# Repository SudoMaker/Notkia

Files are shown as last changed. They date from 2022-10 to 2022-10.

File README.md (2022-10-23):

# Notkia

Files of the [Notkia project on Hackaday](https://hackaday.io/project/185645-notkia).

EE4A1119__22

## Notice
This is only a DIY/maker/hobbyist project. **It has NOTHING to do with the Nokia Corporation.**

**The "NOKIA" logo and trademark belongs to the Nokia Corporation.**

## Contents
**Software** - Kernel patches, config, code, etc

**Hardware** - Hardware design files

**Resources** - Support materials like the docs of used components

## Quick guide
Follow the build instructions on the Hackaday page.

[Firmware download](https://drive.google.com/drive/folders/1oXkI3N4dK0Gwsrb4oEOyaak5tPrkD-Ys?usp=sharing)

When the system is booted, you can connect USB cable and log into the device using the 2nd USB CDC-ACM device. USB RNDIS network is also activated at 192.168.77.2/24 w/o DHCP. SSH login information is root:notkia.

Happy hacking!

## Notes
If you have any questions, feel free to ask on our Twitter / Discord.

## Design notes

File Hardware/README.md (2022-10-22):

# Hardware

## Contents
**V2.0** - The V2.0 Notkia PCB

**SoM_V1.3** - The X1000 SoM used on the V2.0 Notkia PCB

## Usage
### Producing
The Gerber and SMT files can be used to produce the PCBs directly.

### Editing
The standard version of EasyEDA was used to design this project.

At editor, open the document via: Top Menu - File - Open - EasyEDA... , and select the json file, then open it at the editor, you can save it into a project.

## License
CERN-OHL2-S

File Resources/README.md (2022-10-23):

# Resources

## Description

Datasheets and support materials of components that are not easy to find on the Internet are uploaded here.

Information of the rest components can be find on the Internet within a few minutes.

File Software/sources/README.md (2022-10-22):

# Sources

## Contents
**lora** - Mini proof-of-concept LoRa messenger. Hardcoded at 433.92Mhz/22dBm/SF12/62.5kHz.

**t9uinput** - Mini proof-of-concept T9 IME.

**blanker.c** - Zero the VRAM of ST7789. Unbind FBTFT driver before use.

**lvgl_demo.c** - LVGL demo (music player/stress test). Unbind FBTFT driver before use.

## Credits
**ST7789-STM32** - https://github.com/Floyd-Fish/ST7789-STM32

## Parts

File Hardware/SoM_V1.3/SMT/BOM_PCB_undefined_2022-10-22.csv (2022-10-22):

ID | Name | Designator | Footprint | Quantity | Manufacturer Part | Manufacturer | Supplier | Supplier Part | Price
1 | 24MHz | X1 | OSC-SMD_4P-L2.0-W1.6-BL | 1 | Q22FA12800244 | Seiko Epson | LCSC | C255880 | 1.6628
2 | LDO UDFN-4/XDFN-4 大焊盘 | U35,U36 | UDFN-4_L1.0-W1.0-P0.65-BL-EP 焊盘加大 | 2 |  |  | LCSC
3 | 10uF | C5,C6,C8,C9,C12,C16,C18,C19,C28,C116,C120 | C0402 | 11 | CL05A106MQ5NUNC | SAMSUNG | LCSC | C15525 | 0.0328
4 | 22pF | C3,C22,C23,C24,C4,C130 | C0201 | 6 | GRM0335C1H220JA01D | MuRata | LCSC | C76924 | 0.0138
5 | 1uF | C21,C25,C26,C1,C7,C42,C86,C99,C100,C112,C113,C118,C13,C15,C30 | C0201 | 15 | JMK063ABJ105MP-F | TAIYO YUDEN | LCSC | C87143 | 0.0117
6 | 330K | R10,R13,R14,R3,R1,R11 | R0201 | 6 | RC0201FR-07330KL | YAGEO | LCSC | C142017 | 0.0061
7 | 1MΩ | R15,R6 | R0201 | 2 | RTT011004FTH | RALEC | LCSC | C102686 | 0.0062
8 | 4.7kΩ | R16 | R0201 | 1 | 0201WMF4701TEE | Uniroyal Elec | LCSC | C270346 | 0.005
9 | 10MΩ | R17 | R0201 | 1 | 0201WMF1005TCE | Uniroyal Elec | LCSC | C270818 | 0.0214
10 | 32.768kHz | X2 | FC-12M_L2.0-W1.2 | 1 | FC-12M32.768KHZ7PF20PPM | EPSON | LCSC | C99009 | 1.7615
11 | 1K | R7 | R0201 | 1 | RC0201JR-071KL | YAGEO | LCSC | C131396 | 0.0044
12 | 240Ω | R8 | R0201 | 1 | RTT01241JTH | RALEC | LCSC | C102710 | 0.0039
13 | 43.2Ω | R12 | R0201 | 1 | RTT0143R2FTH | RALEC | LCSC | C158511 | 0.0062
14 | 178kΩ | R4 | R0201 | 1 | 0201WMF1783TCE | Uniroyal Elec | LCSC | C270786 | 0.0098
15 | 100 | R9 | R0201 | 1 | RC0201FR-07100RL | YAGEO | LCSC | C77623 | 0.0056
16 | 100nF | C11,C2,C10,C33,C46,C48,C49,C51,C82,C98,C101,C117,C129,C131,C14 | C0201 | 15 | CL03A104KQ3NNNC | SAMSUNG | LCSC | C160831 | 0.0036
17 | 10nF | C32,C80,C102,C132,C97 | C0201 | 5 | GRM033R71E103KE14D | MuRata | LCSC | C85930 | 0.011
18 | 2.2uH | L1,L2,L3 | IND-SMD_L2.0-W1.6 | 3 | WPN201610U2R2MTY01 | Sunlord | LCSC | C370597 | 0.3682
19 | 100kΩ | R2 | R0402 | 1 | 0402WGF1003TCE | UniOhm | LCSC | C25741 | 0.0029
20 | 200kΩ | R5 | R0402 | 1 | 0402WGF2003TCE | UniOhm | LCSC | C25764 | 0.0029
21 | 124kΩ | R59 | R0402 | 1 | 0402WGF1243TCE | UniOhm | LCSC | C36777 | 0.0032
22 | 115kΩ | R60 | R0402 | 1 | 0402WGF1153TCE | UniOhm | LCSC | C25747 | 0.0036
23 | X1000 | U1 | BGA-190_L13.0-W13.0-R16-C16-P0.8-TR | 1 | X1000 | ingenic(君正) | LCSC | C2689394 | 47.65
24 | TPS63000DRCR | U32 | SON-10_L3.1-W3.1-P0.50-TL-EP | 1 | TPS63000DRCR | TI | LCSC | C24966 | 110.32
25 | RT8010GQW | U33,U34 | WDFN-6_L2.0-W2.0-P0.65-BL-EP | 2 | RT8010GQW | RICHTEK | LCSC | C130803 | 2.15
26 | 10kΩ | RN1 | RES-ARRAY-SMD_0402-8P-L2.0-W1.0-BL | 1 | 4D02WGJ0103TCE | UniOhm | LCSC | C25725 | 0.0318
27 | W25Q256JVEIQ | U16 | WSON-8_L6.0-W8.0-P1.27-BL-EP | 1 | W25Q256JVEIQ | WINBOND(华邦) | LCSC | C2682312 | 11.28

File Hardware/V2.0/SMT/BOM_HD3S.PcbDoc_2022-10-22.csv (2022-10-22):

ID | Name | Designator | Footprint | Quantity | Manufacturer Part | Manufacturer | Supplier | Supplier Part | Price
1 | JW_S-5012-A | J17 | JW_S-5012-A | 1
2 | N168X_Key | K1,K2,K3,K4,K5,K6,K7,K8,K9,K10,K11,K12,K13,K14,K15,K16,K17,K18,K19,K20,K21 | N168X_KEY | 21
3 | TZ-P2-0603WYS1-1.1T | LED1,LED2 | LED-SMD_L1.6-W1.2-RD | 2 | TZ-P2-0603WYS1-1.1T | TUOZHAN | LCSC | C916072 | 0.1172
4 | GPS1003 | ANT2 | ANT-SMD_L10.0-W3.0 | 1 | GPS1003 | Rainsun microwave Tech | LCSC | C239243 | 6.76
5 | 1uF | C16,C43,C46,C47,C48,C50,C15,C28,C32,C21,C22,C26,C27,C20,C34,C5,C6,C7,C23 | C0402 | 19 | CL05A105KA5NQNC | SAMSUNG | LCSC | C52923 | 0.0203
6 | WD3153D-10/TR | U3 | DFN-10_L2.0-W2.0-P0.40-BL-EP | 1 | WD3153D-10/TR | WILLSEMI(韦尔) | LCSC | C506151 | 0.3361
7 | TP | Q6,Q5,Q3,Q4 | TP | 4 | TP
8 | UBX-G7020-KT | U18 | UBX-G7020-KT | 1
9 | 47pF | C33 | C0402 | 1 | 0402CG470J500NT | FH | LCSC | C1567 | 0.0054
10 | 2.7pF | C41 | C0402 | 1 | 0402CG2R7C500NT | FH | LCSC | C1561 | 0.0071
11 | 4.7uF | C24,C25,C35,C37,C44,C49,C59,C60,C62,C64,C65,C66,C71,C74,C75,C122 | C0402 | 16 | CL05A475MP5NRNC | SAMSUNG | LCSC | C23733 | 0.0327
12 | 2.2uF | C45 | C0402 | 1 | CL05A225MQ5NSNC | SAMSUNG | LCSC | C12530 | 0.012
13 | 8.2nH | L1 | IND-SMD_L1.0-W0.5-2 | 1 | LQW15AN8N2G00D | MuRata | LCSC | C84404 | 0.2212
14 | 2.2uH | L3 | L0806 | 1 | LQM2MPN2R2NG0L | MuRata | LCSC | C83998 | 0.4232
15 | 26MHz | X2 | OSC-SMD_4P-L3.2-W2.5-BL_1XTV | 1 | 1XTW26000MAA | KDS Daishinku | LCSC | C213404 | 6.34
16 | 2.2K | R1,R2,R12,R13 | R0402 | 4 | 0402WGF2201TCE | UniOhm | LCSC | C25879 | 0.0029
17 | X1000_Nano | U1 | X1000_NANO | 1 | X1000_Nano | SudoMaker
18 | VRD1528MTX | U33 | SOT-23-6_L2.9-W1.6-P0.95-LS2.8-BL | 1 | VRD1528MTX | AnaSem | LCSC | C697914 | 0.5386
19 | FH34SRJ-12S-0.5SH(50) | FPC1 | FFC-SMD_12P-P0.50_FH34SRJ-12S-0.5SH | 1 | FH34SRJ-12S-0.5SH(50) | Hirose | LCSC | C424659 | 1.0982
20 | 33kΩ | RN3,RN1,RN2 | RES-ARRAY-SMD_0402-8P-L2.0-W1.0-BL | 3 | WA04X333JTL | Walsin Tech Corp | LCSC | C431861 | 0.0305
21 | 47uF | C11,C18 | C0805 | 2 | CL21A476MQYNNNE | SAMSUNG | LCSC | C16780 | 0.0682
22 | RFANT3216120A5T | ANT1 | FILTER-SMD_1206-2P-L3.2-W1.6-L | 1 | RFANT3216120A5T | Walsin Tech Corp | LCSC | C127629 | 0.536
23 | 100nF | C14,C40,C42,C38,C19,C1,C4,C8,C10,C12 | C0402_NEW | 10 | CL05B104KO5NNNC | SAMSUNG | LCSC | C1525 | 0.0062
24 | PCA9555RGERG4 | U2,U8,U141 | VQFN-24_L4.0-W4.0-P0.50-TL-EP2.4 | 3 | PCA9555RGERG4 | TI(德州仪器) | LCSC | C2669780 | 9.57
25 | FH34SRJ-24S-0.5SH(50) | CONN1 | FFC-SMD_24P-P0.50_FH34SRJ-24S-0.5SH | 1 | FH34SRJ-24S-0.5SH(50) | Hirose | LCSC | C324726 | 1.114
26 | HSST3139 | Q1,Q2 | SOT-523-3_L1.6-W0.8-P1.00-LS1.6-BR | 2 | HSST3139 | HUASHUO(华朔) | LCSC | C700948 | 0.3076
27 | 1TS026A-1800-0553-CT | SW1 | SW-SMD_4P-L2.6-W1.6-P0.75-LS3.0 | 1 | 1TS026A-1800-0553-CT | HYP(鸿源精密) | LCSC | C913786 | 0.5711
28 | 33kΩ | R7,R18,R3,R29,R4,R8,R10,R11 | R0402 | 8 | 0402WGF3302TCE | UniOhm | LCSC | C25779 | 0.0029
29 | HJ_LORA | U64 | HJ_LORA | 1
30 | MKDV32GCL-STL | U16 | W-PDFN-8_L8.0-W6.0-P1.27-TL-EP | 1 | MKDV32GCL-STL | MK(米客方德) | LCSC | C2844071 | 53.05
31 | MHS110FRGBCT | LED16 | LED-ARRAY-SMD_MHS110FRGBCT | 1 | MHS110FRGBCT | MEIHUA(美华科技) | LCSC | C496820 | 0.4385
32 | N68_BATJ | BAT1 | N68_BATJ | 1
33 | TYPE-611S-T3 | USB1 | USB-SMD_TYPE-611S-T3 | 1 | TYPE-611S-T3 | Yuandi(台湾元迪) | LCSC | C2874595 | 0.727
34 | 1N5819WS | D3,D1 | SOD-323_L1.8-W1.3-LS2.5-RD | 2 | 1N5819WS | Guangdong Hottech | LCSC | C191023 | 0.101
35 | RX8900CE | U204 | RX8130CE/RX8900CE | 1 | RX8900CE | EPSON
36 | 1kΩ | R20 | R0603 | 1 | 0603WAF1001T5E | UniOhm | LCSC | C21190 | 0.0027
37 | 10uF | C2,C9,C13,C39,C134 | C0402 | 5 | CL05A106MQ5NUNC | SAMSUNG | LCSC | C15525 | 0.0328
38 | 3.3K | R19 | R0402 | 1 | 0402WGF3301TCE | UniOhm | LCSC | C25890 | 0.0029
39 | 100nF | C29,C30,C36 | C0402 | 3 | CL05B104KO5NNNC | SAMSUNG | LCSC | C1525 | 0.0062
40 | 12.288MHz | X1 | OSC-SMD_4P-L2.0-W1.6-BL_SIT1602BI | 1 | OT201624MJBA4SL | YXC扬兴科技 | LCSC | C725986 | 4.41
41 | 1nF | C31 | C0402 | 1 | 0402B102K500NT | FH | LCSC | C1523 | 0.0061
42 | YMU762 | U140 | C-PK32QP-2 | 1
43 | 20kΩ | R14,R15,R16,R17 | R0402 | 4 | 0402WGF2002TCE | UniOhm | LCSC | C25765 | 0.0029
44 | BCT8890ELA-TR | U129,U130 | DFN-8_L2.0-W2.0-P0.50-BL-EP-1 | 2 | BCT8890ELA-TR | BROADCHIP(广芯电子) | LCSC | C2924400 | 1.0485
45 | SHTC3 | U41 | SENSORM-SMD_4P-L2.0-W2.0-P1.00 | 1 | SHTC3 | Sensirion | LCSC | C194656 | 5.88
46 | FUSB301TMX | U135 | TMLP-10_L1.6-W1.2-P0.40 | 1 | FUSB301TMX | ON | LCSC | C132290 | 7.64
47 | 0Ω | R49,R54 | R0402 | 2 | 0402WGF0000TCE | UniOhm | LCSC | C17168 | 0.0028
48 | A_P6214 | U48 | AP6214A | 1
49 | NAU88C22YG | U128 | QFN-32_L5.0-W5.0-P0.50-BL-EP3.4 | 1 | NAU88C22YG | NUVOTON | LCSC | C100123 | 6.7
50 | 22uF | C135,C136 | C0603 | 2 | CL10A226MQ8NRNC | SAMSUNG | LCSC | C59461 | 0.0292
51 | 1uH | L4 | IND-SMD_L2.5-W2.0_252012 | 1 | HHEI252010A-1R0M-Q8 | chilisin(奇力新) | LCSC | C910025 | 0.5405
52 | BQ25890RTWR | U32 | WQFN-24_L4.0-W4.0-P0.50-BL-EP | 1 | BQ25890RTWR | TI | LCSC | C130451 | 37.44
53 | MAX17048G+T10 | U39 | DFN-8_L2.0-W2.0-P0.50-BL-EP | 1 | MAX17048G+T10 | MAXIM(美信) | LCSC | C2682616 | 6.35
54 | 47nF | C3 | C0402 | 1 | 0402B473K250CT | Walsin Tech Corp | LCSC | C314287 | 0.008
55 | N126x_EAR | J1,J2 | N126X_EAR | 2
56 | WMM7037AT2 | MIC1 | MIC-SMD_L3.8-W3.00-TL | 1 | WMM7037AT2 | WEIER | LCSC | C140705 | 2.39
57 | 3.3uH | L2 | L0805 | 1 | MPL2012S3R3MHT | Sunlord | LCSC | C98331 | 0.1947

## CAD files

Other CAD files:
Resources/2.0 S-5012-A(3).dwg

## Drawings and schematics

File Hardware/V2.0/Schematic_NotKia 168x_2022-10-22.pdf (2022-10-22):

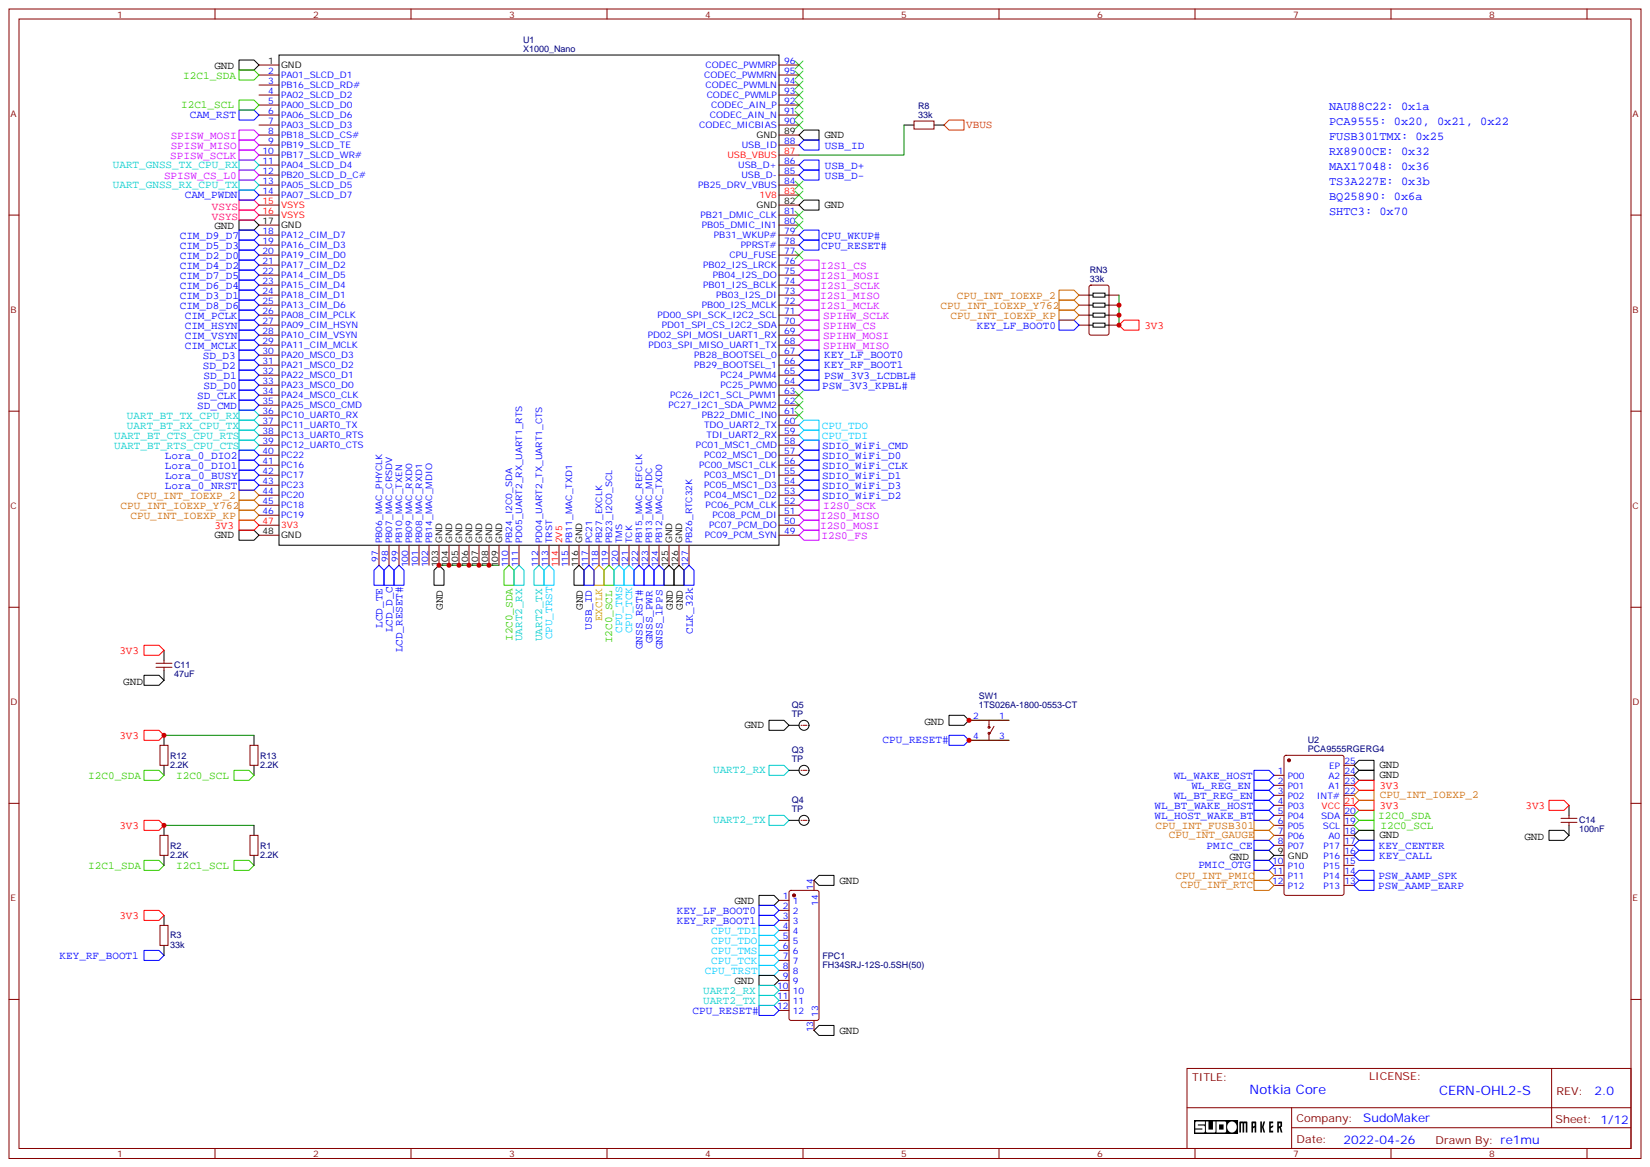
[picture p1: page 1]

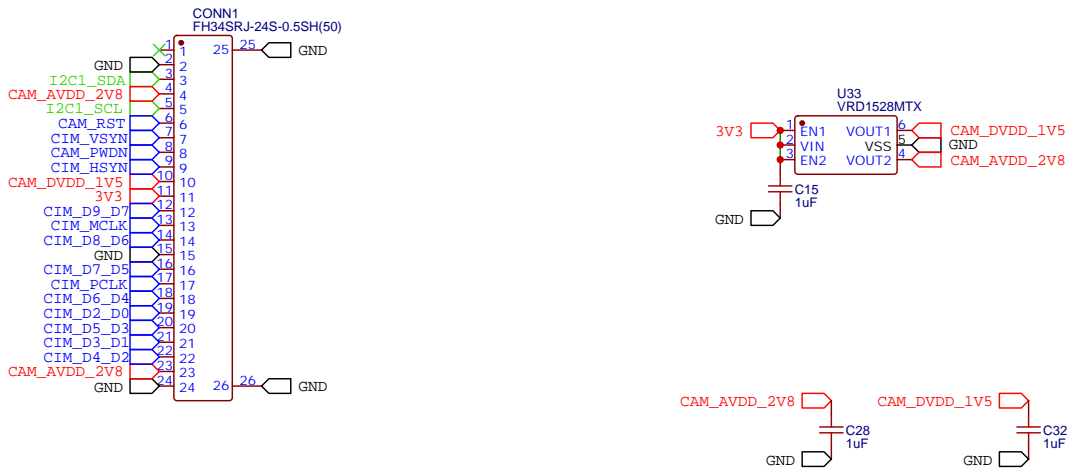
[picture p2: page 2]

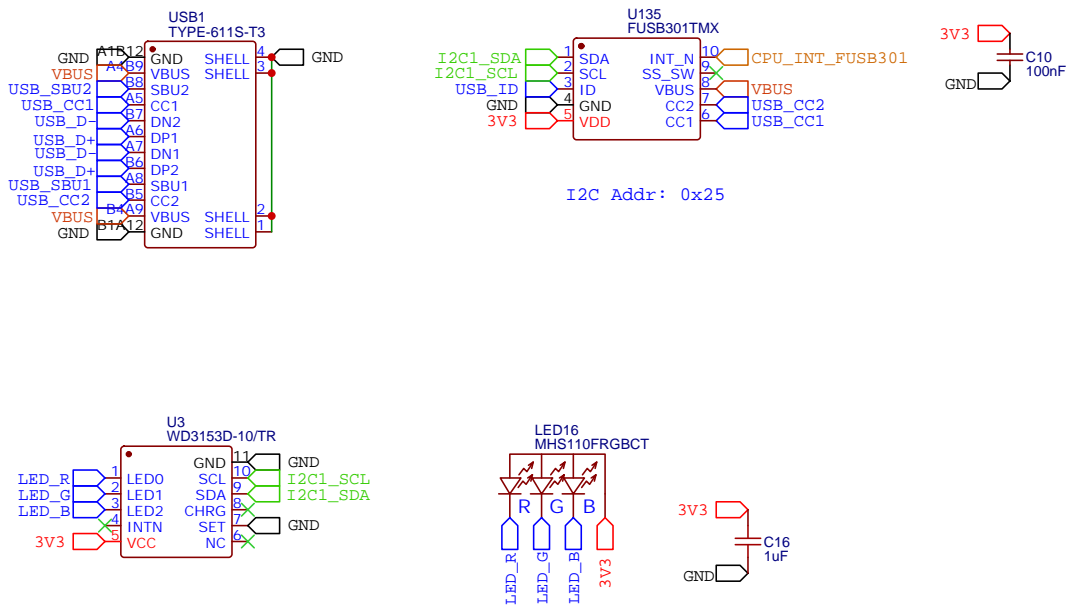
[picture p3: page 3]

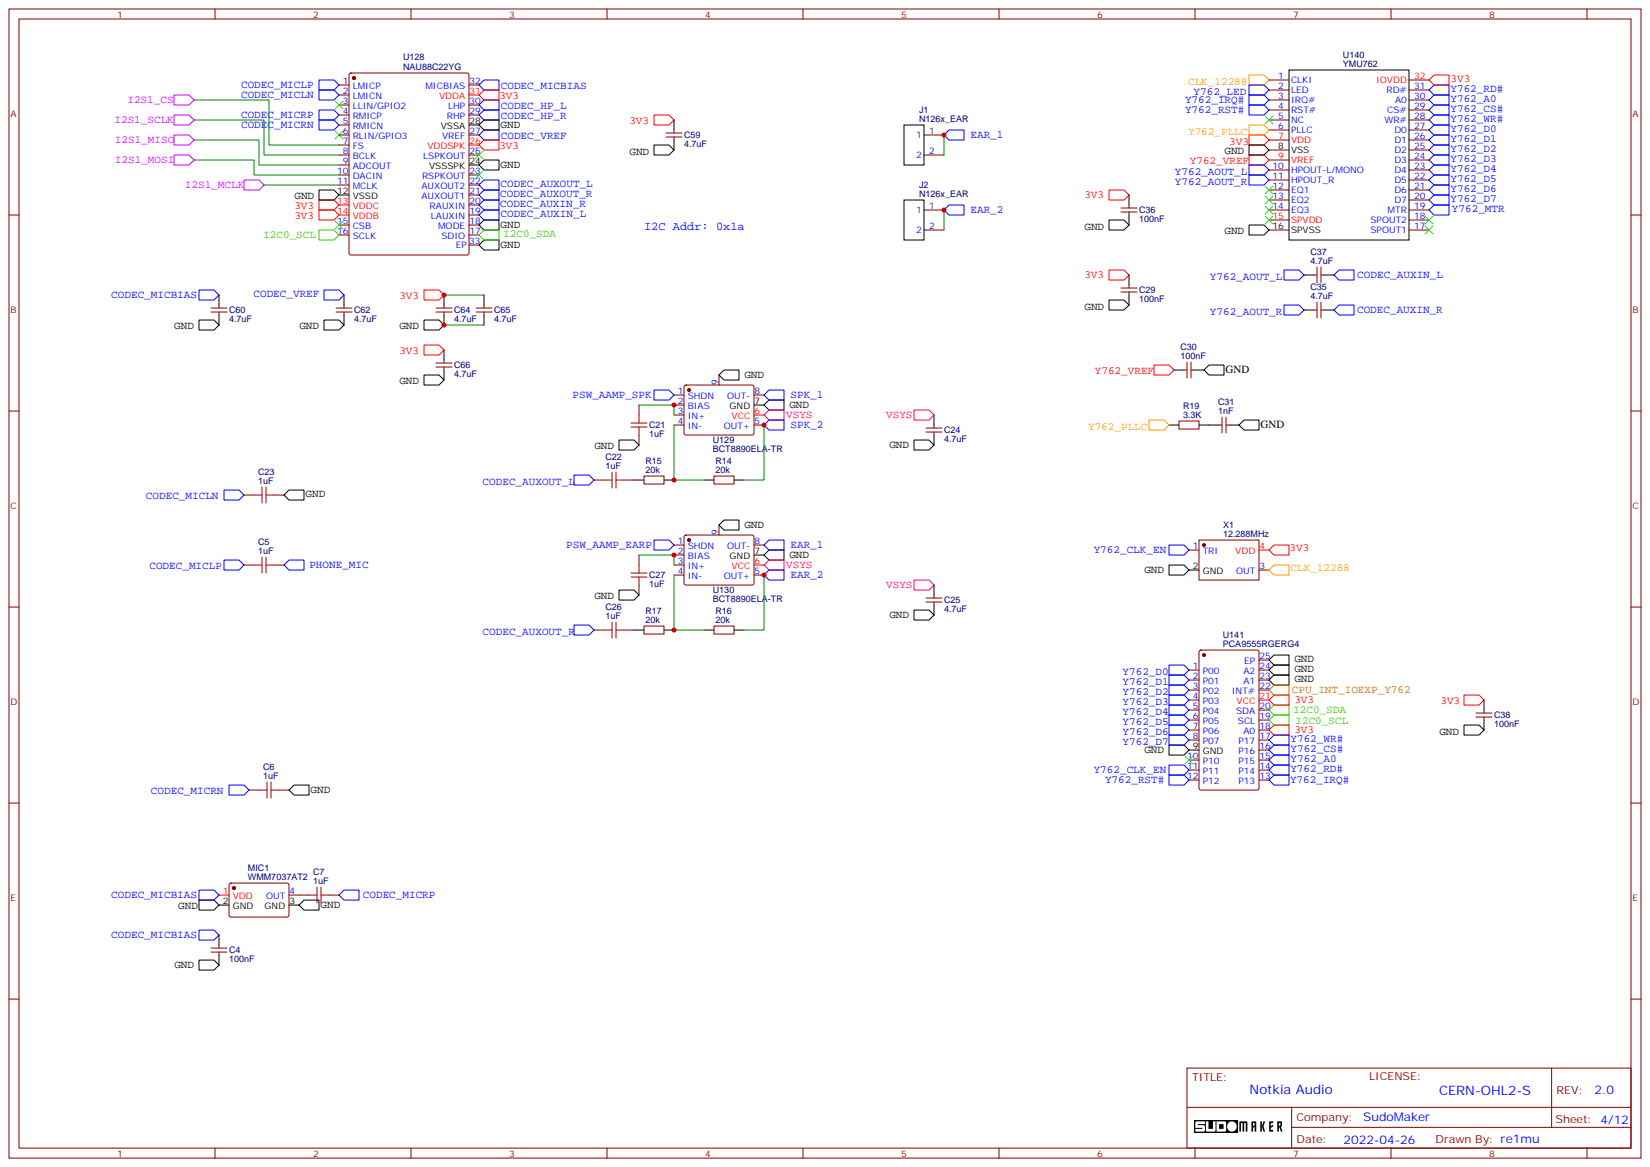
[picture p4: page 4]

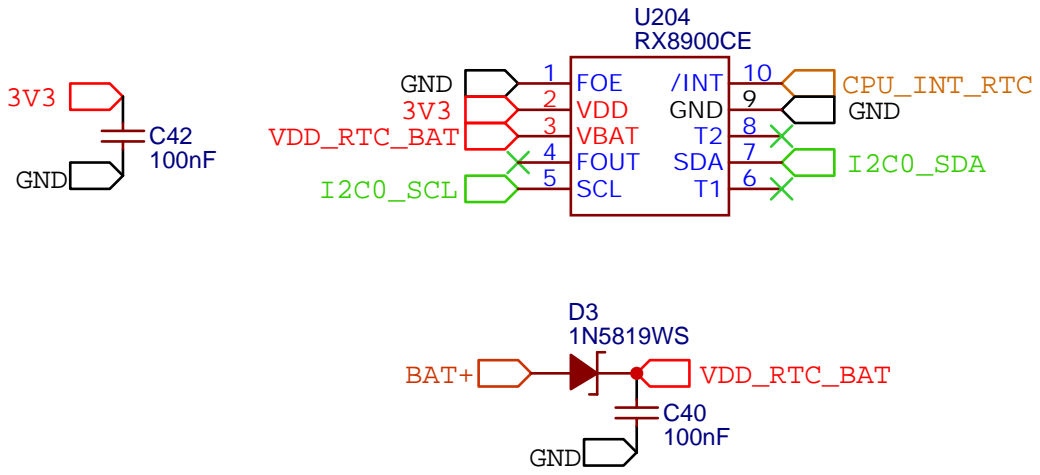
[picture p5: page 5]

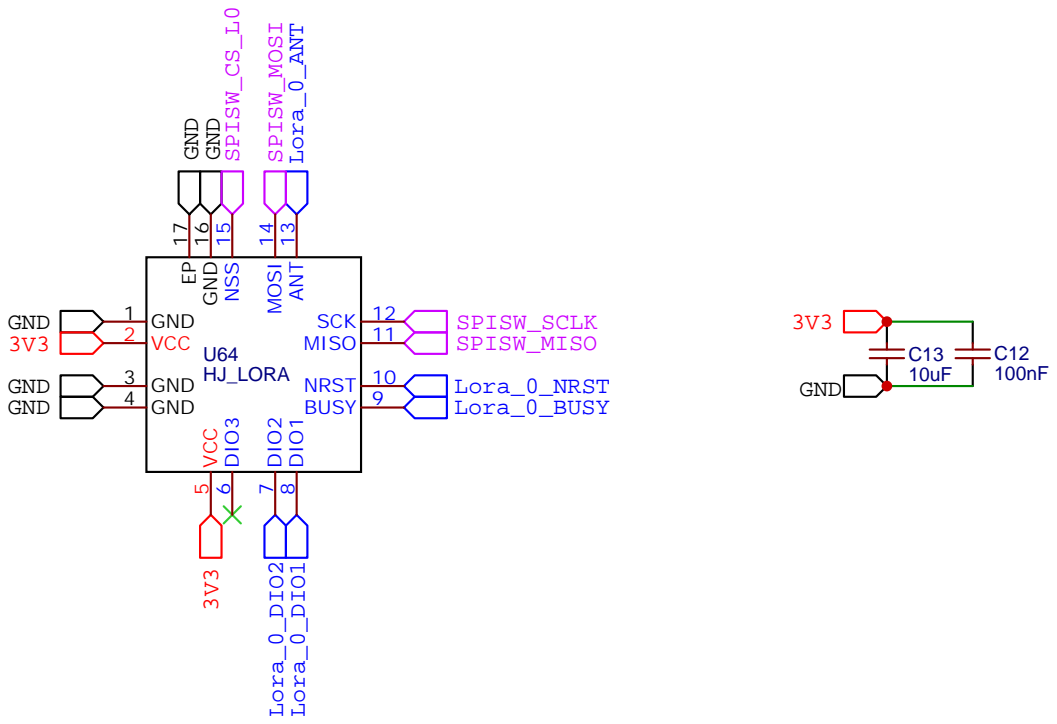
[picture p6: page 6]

NSS 15 GND 16 EP 17 GND

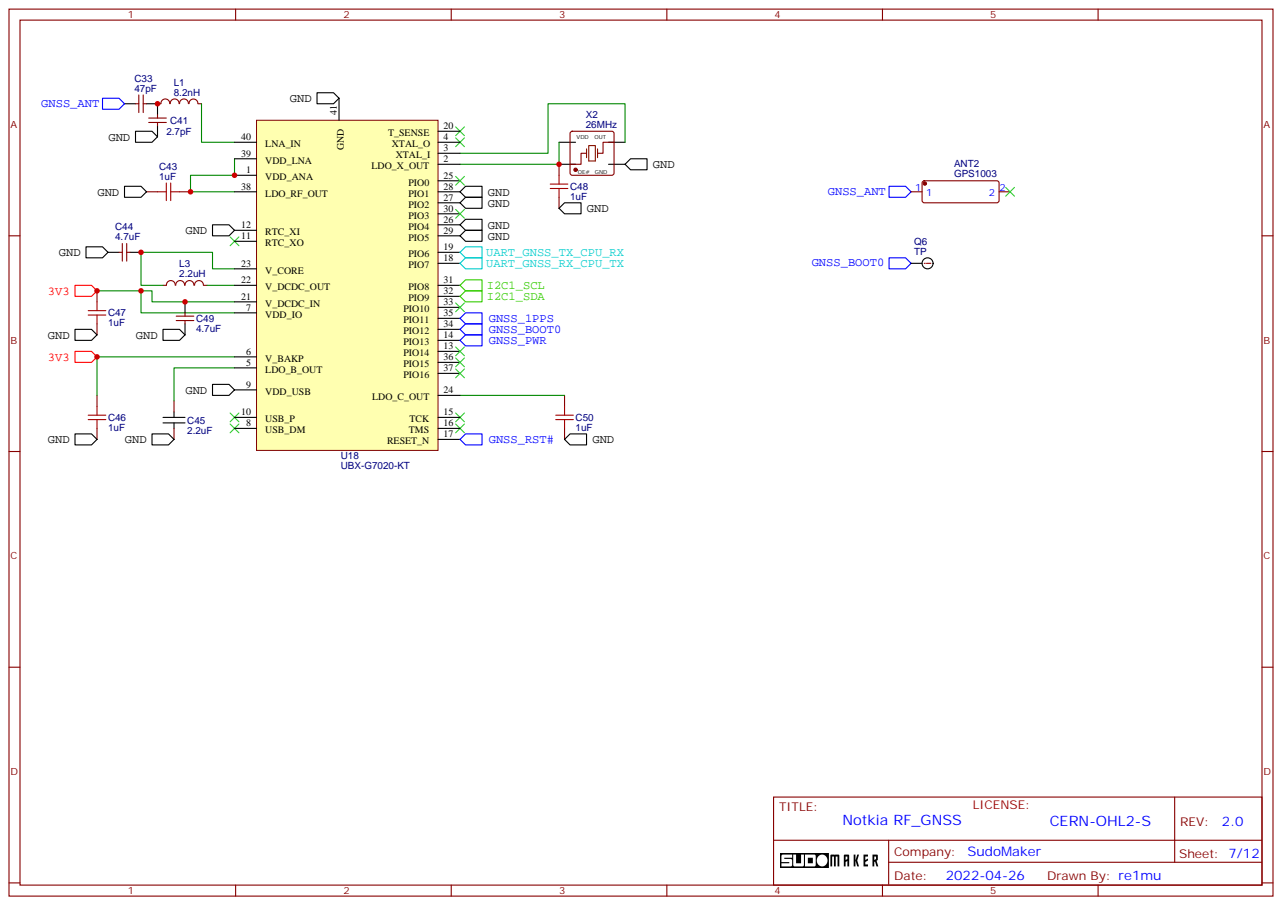
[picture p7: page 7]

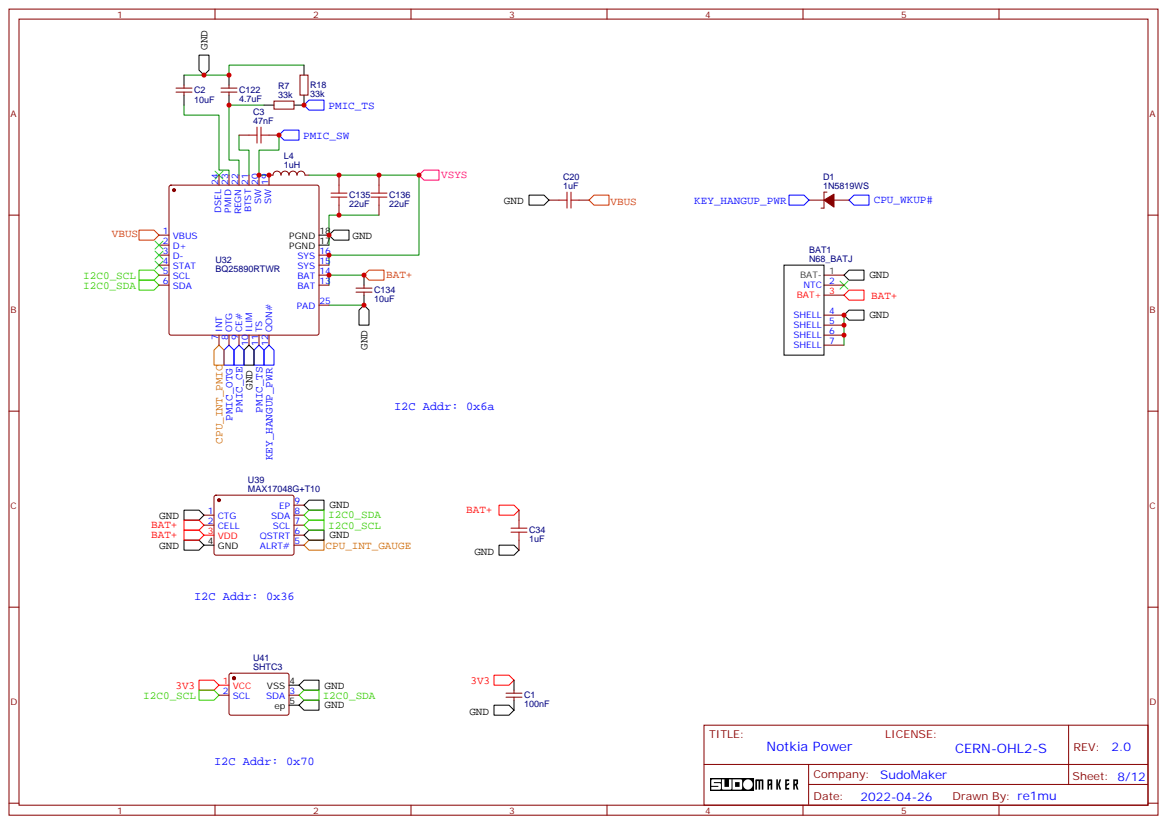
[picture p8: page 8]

BAT 13 BAT 14 SYS 15 SYS 16 PGND 17 PGND 18

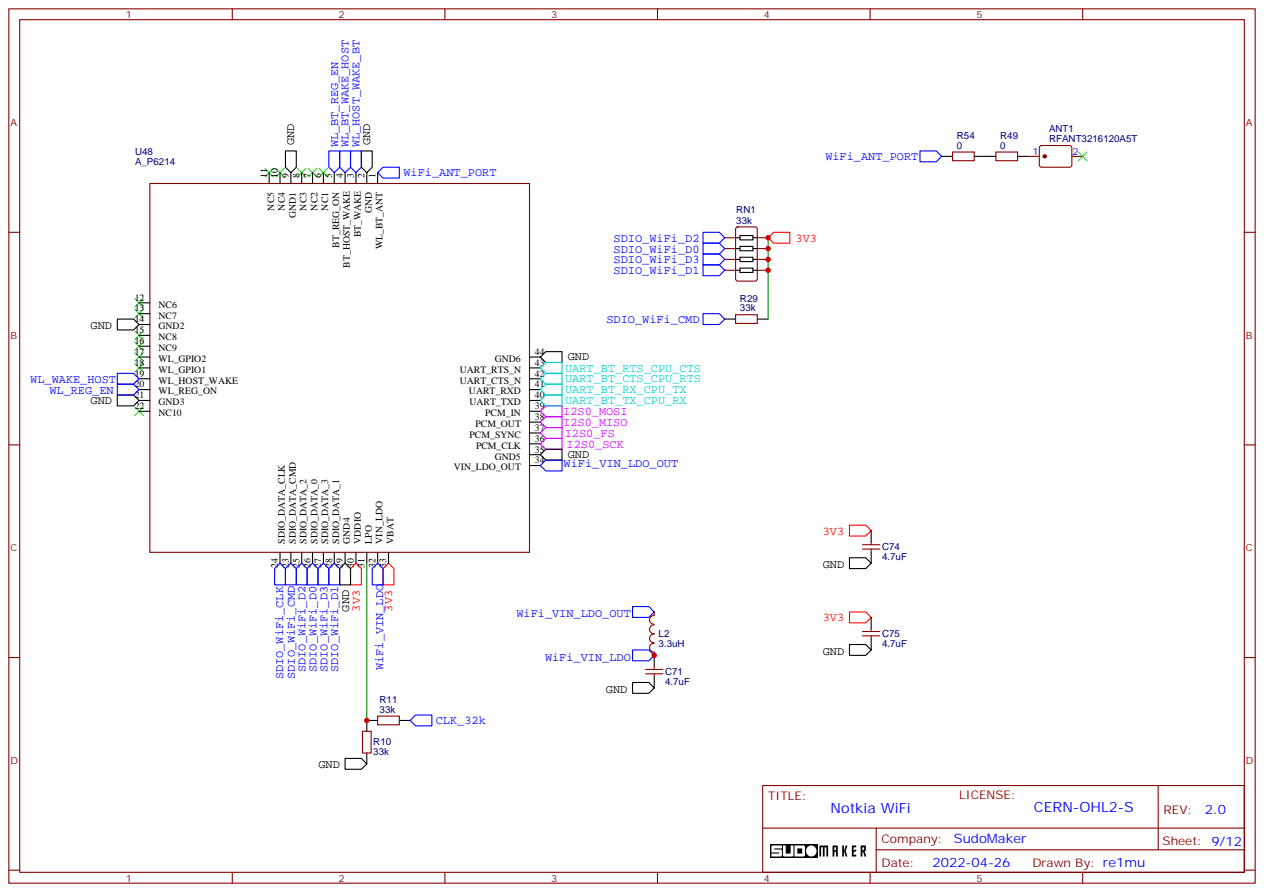
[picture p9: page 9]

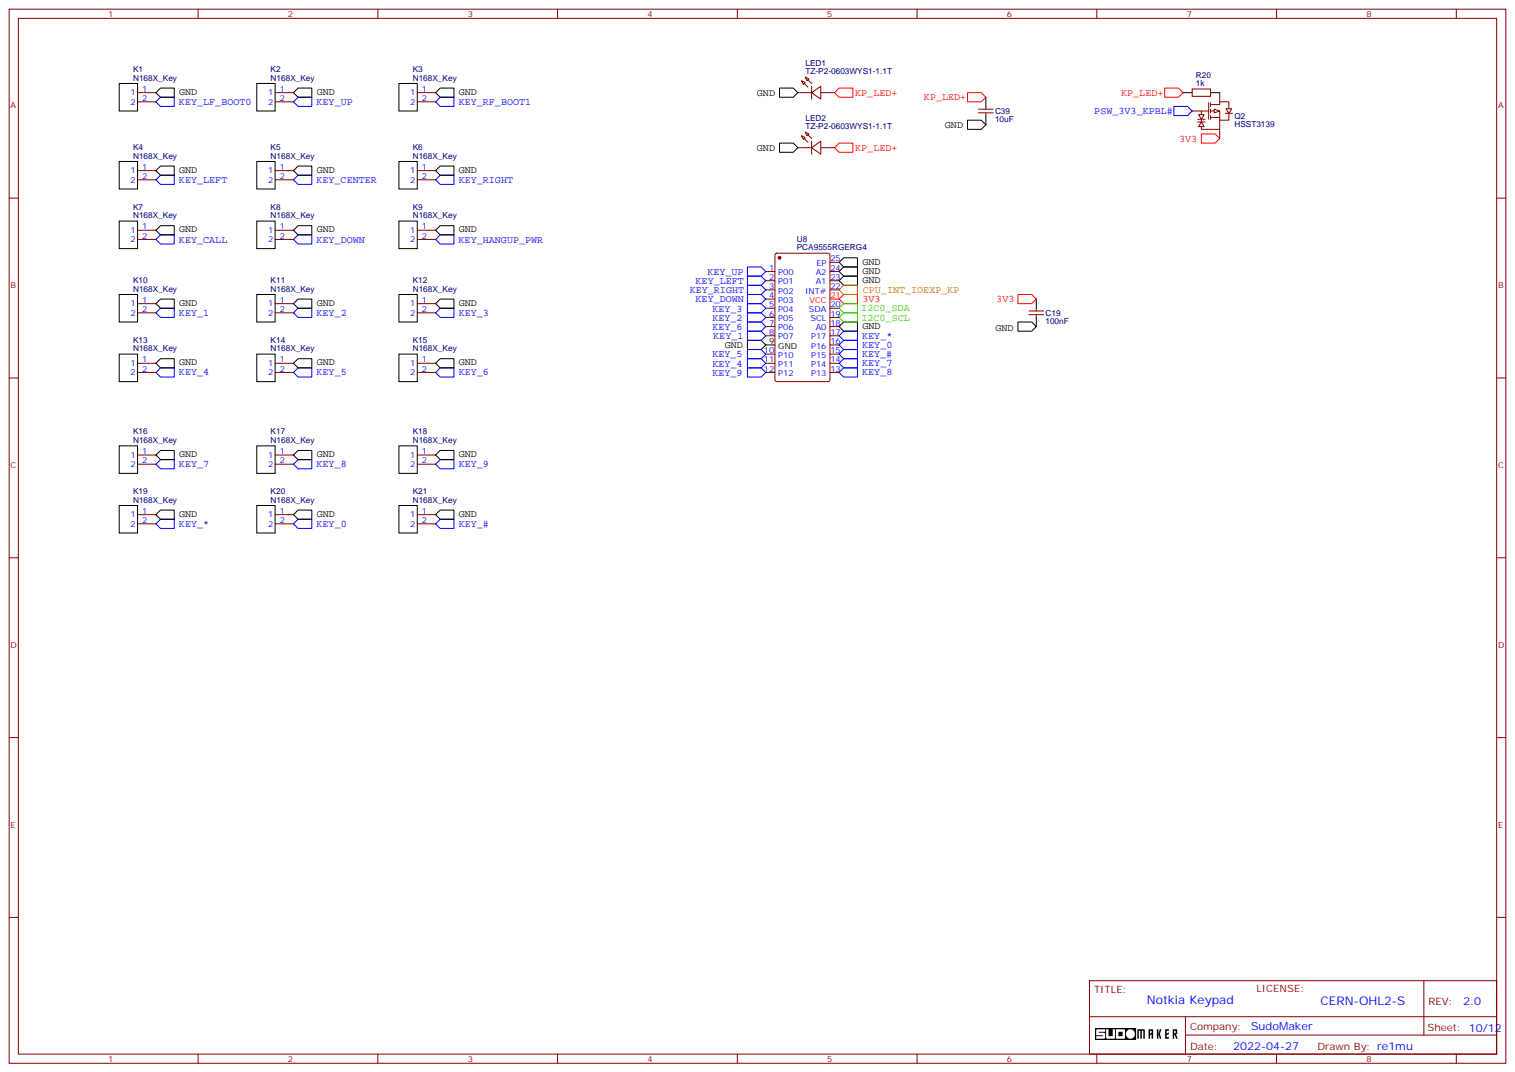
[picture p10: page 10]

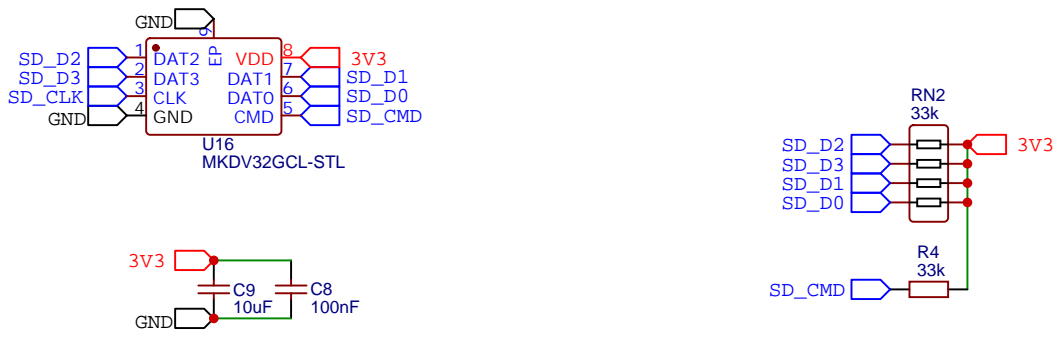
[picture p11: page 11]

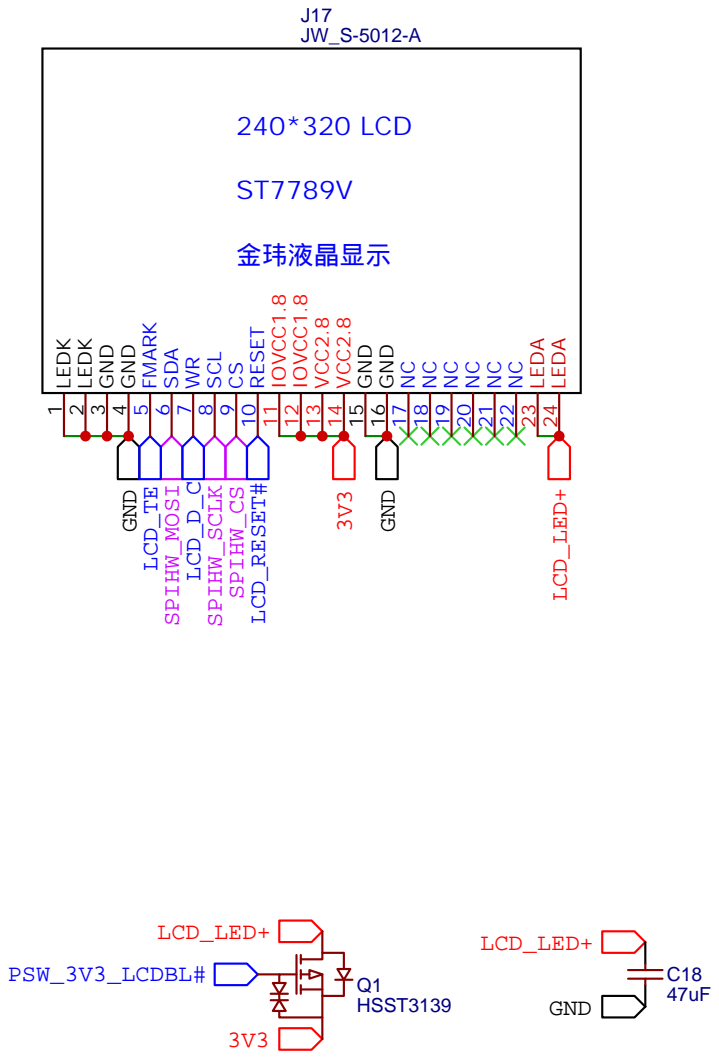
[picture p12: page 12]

LEDA 24 LEDA 23 NC 22 NC 21 NC 20 NC 19 NC 18 NC 17 GND 16 GND 15


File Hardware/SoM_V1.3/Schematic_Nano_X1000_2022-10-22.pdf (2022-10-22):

UART2_TXD_UART1_CTS_PD04 N2 UART2_RXD_UART1_RTS_PD05 N1 pad_TRST_ K3 TDO_UART2_TXD G1 TDI_UART2_RXD G2 TCK L3 TMS M3 LPDDR_VDD E6 LPDDR_VDD F6 LPDDR_VDD G6 LPDDR_VSS J7 LPDDR_VSS K7 LPDDR_VSS L7 LPDDR_VDDQ F5 LPDDR_VDDQ G5 LPDDR_VDDQ H5 LPDDR_VDDQ H6 LPDDR_VDDQ H7 LPDDR_VSSQ J5 LPDDR_VSSQ J6 LPDDR_VSSQ K5 LPDDR_VSSQ K6 LPDDR_VSSQ L6 ZQ B9 VREF0 A8 VDDMEM E7 VDDMEM E8 VDDMEM F7 VDDMEM F8 VDDMEM G7 VDDMEM G8 VSSMEM E9 VSSMEM E10 VSSMEM F9 VSSMEM F10 VSSMEM G9 VSSMEM G10 VDDIO K11 VDDIO K12 VDDIO L12 VDDIO_5T N6 VSS J10 VSS K8 VSS K9 VSS K10 VSS L8 VSS L9 VSS L10 VSS L11 VSS M8 VSS M9 VSS M10 VDD F11 VDD G11 VDD G12 VDD H10 VDD H11 VDD H12 VDD J11 VDD J12 CODEC_AVDD P16 CODEC_AVSS P14 CODEC_VREFP P15 VCAP T15 AIP R16 AIN R15 MICBIAS R14 VDDIO_CODEC L16 VSSIO_CODEC M14 CODEC_PWMLP N15 CODEC_PWMLN N16 COEDC_PWMRP M15 CODEC_PWMRN M16 USB_DP0(OTG_DP) R12 USB_DM0(OTG_DM) T12 USB_VBUS(OTG_VBUS) P13 USB_ID(OTG_ID) P11 OTG_TXR_RKL R13 AVDOTG T14 AVSOTG R11 AVDOTG25 T13 AVDEFUSE H2 EXCLK_XI(EXCLK_I) T10 EXCLK_XO(EXCLK_O) R10 PLL_DVDD T9 PLL_DVSS P9 PLL_AVDD R9 PLL_AVSS P10 RTCLK R8 XRTCLK T8 PWRON R7 PPRST_ P6 TEST_TE P7 LDOOUT T7 VSSRTC N7 VDDRTC T6





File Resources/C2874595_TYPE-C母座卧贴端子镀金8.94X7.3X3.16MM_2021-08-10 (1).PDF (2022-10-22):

G ABCDEFGHIJ; IADFHJ Yuandi Electronics Co,Ltd RoHS
